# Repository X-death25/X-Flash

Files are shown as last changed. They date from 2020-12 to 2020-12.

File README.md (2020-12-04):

# X-Flash
An Open Source CPLD based Sega Megadrive/Genesis Flash Cart 
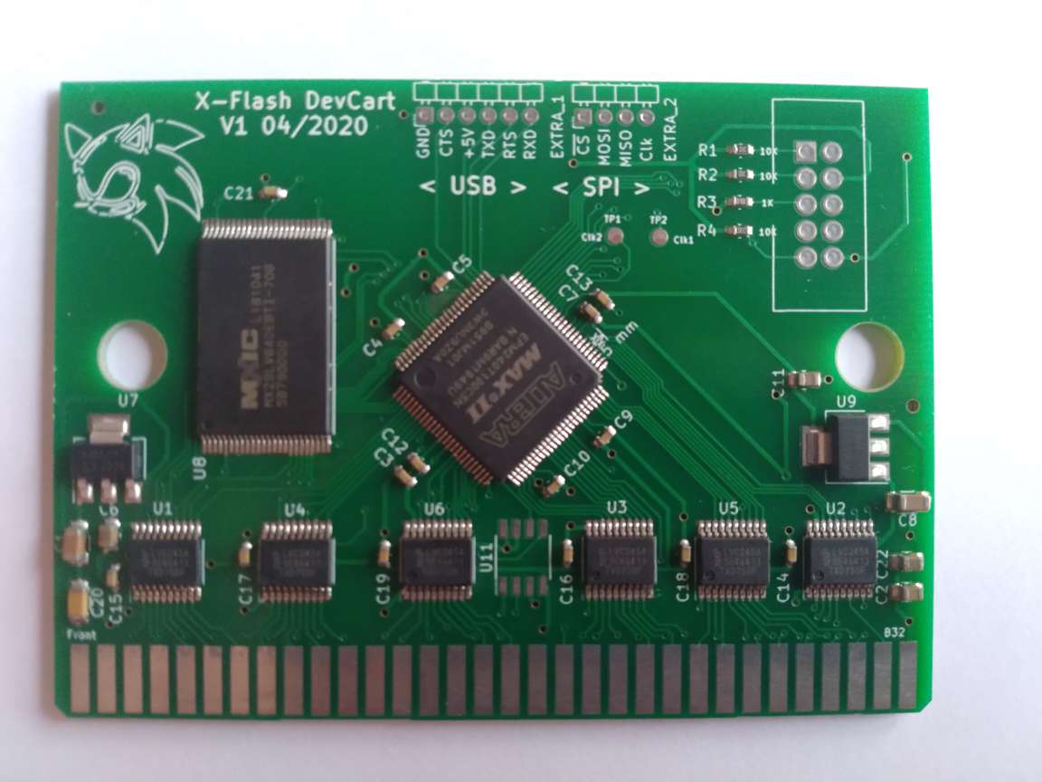
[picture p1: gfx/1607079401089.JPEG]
Xflash_pcb


What is it ?
-----

X-flash is my Sega Megadrive developpement cartridge.
I use it for some research and do all of my hardware test.
It's based on the good old EPM240 and a 64Mb flash memory

Product Feature :
-----

    Rewritable 64 Mb Flash ROM
    192 Macrocells CPLD
    Clean 5V <> 3.3V level shifting
    7 GPIO for user
    Open Source Hardware & Software & PCB

Cartridge supported :
-----
    Classic 32Mb cartridge ( no mapper )

How to use it :
-----

Just flash the needed core into the CPLD and cartridge will works in the same way as an original.
You can reflash memory with any compatible Megadrive reader ( for exemple MD Dumper / Krikkz / Sanni cart Reader )

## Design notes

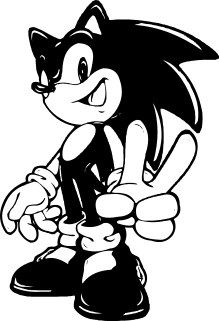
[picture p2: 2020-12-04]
pcb/modules/sonic.png

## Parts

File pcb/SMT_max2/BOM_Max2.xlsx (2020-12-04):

Comment | Designator | Footprint | LCSC Part
Level Shifter | U1,U2,U3,U4,U5,U6 | 74LVC245 | C6082
Flash 64Mb | U8 | MX29LV640 | C30076
Regulateur 3,3V | U7,U9 | AMS1117 3,3V | C6186
MAX2 CPLD | U10 | EPM240T100C5N | C10041
100nF SMD 0603 | C3 ,C4,C5,C7,C9,C10,C12,C13,C14,C15,C16,C17,C18,C19,C21 | 0603_CD | C14663
10µF SMD 1206 | C1,C8 | 0603_CR | C13585
22µF SMD 0805 | C6,C11,C2,C22 | 0603_CR | C45783
100nF SMD 1206 | C20 | 1206_C | C24497
10K SMD 0603 | R1,R2,R4 | R_0603 | C25804
1K SMD 0603 | R3 | R_0603 | C21190

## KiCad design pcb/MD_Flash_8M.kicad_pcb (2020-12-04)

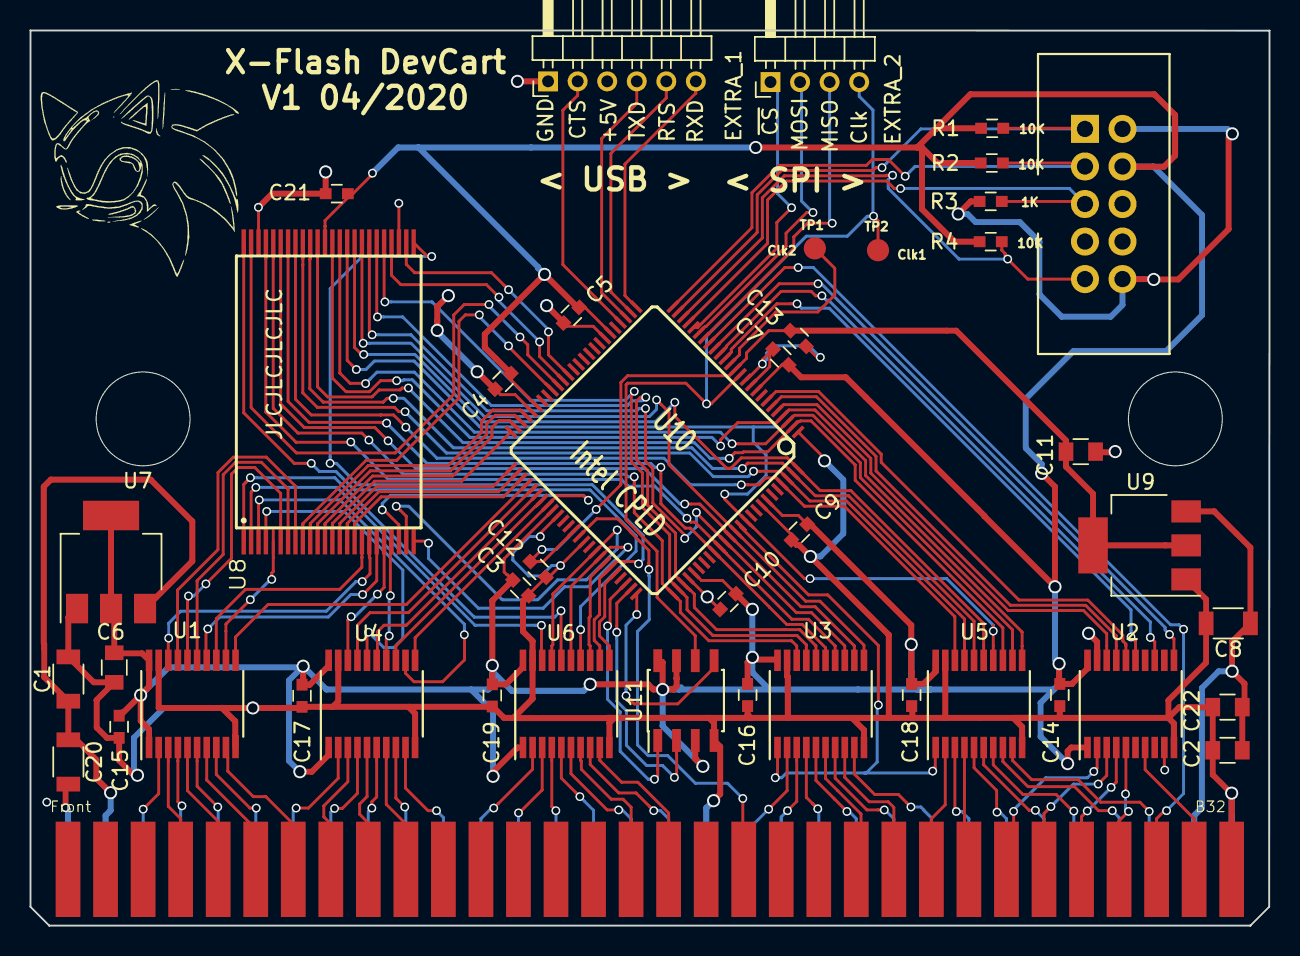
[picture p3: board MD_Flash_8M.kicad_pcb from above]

Board: 2 copper layers, 83.8 x 60.6 mm, 41 parts (0 on the bottom side), 116 nets.

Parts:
C1, C8, C20: 1206_C; C_1206
C2, C6, C11, C22: C_0805
C3, C4, C5, C7, C9, C10, C12, C13, C14, C15, C16, C17, C18, C19, C21: 0603_CD; C_0603
EXTRA_1: Pin_Header_Angled_1x06_Pitch2.00mm
EXTRA_2: Pin_Header_Angled_1x04_Pitch2.00mm
J1: 0; AVR-JTAG-ICE
MD_Connector1: MD_Connector_H; MEGADRIVE_PCB
R1, R2, R3, R4: R_0603; C_0603
U1, U2, U3, U4, U5, U6: 74LVC245; TSSOP-20_4.4x6.5mm_Pitch0.65mm
U7, U9: SOT-223
U8: MX29LV640; S29GL064
U10: Intel CPLD; TQFP_100
U11: AT25xxx; SOIC-8_3.9x4.9mm_Pitch1.27mm

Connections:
5V1: C2.2, C8.1, C22.2, MD_Connector1.A31, U9.3
5V2: C1.1, C20.1, MD_Connector1.A2, U7.3
A1: MD_Connector1.A17, U6.8
A2: MD_Connector1.A15, U6.5
A3: MD_Connector1.A13, U6.3
A4: MD_Connector1.A11, U4.9
A5: MD_Connector1.A9, U4.6
A6: MD_Connector1.A7, U4.2
A7: MD_Connector1.A5, U1.6
A8: MD_Connector1.A3, U1.2
A9: MD_Connector1.B4, U1.3
A10: MD_Connector1.B5, U1.5
A11: MD_Connector1.A4, U1.4
A12: MD_Connector1.A6, U1.8
A13: MD_Connector1.A8, U4.4
A14: MD_Connector1.A10, U4.8
A15: MD_Connector1.A12, U6.2
A16: MD_Connector1.A14, U6.4
A17: MD_Connector1.A16, U6.6
A18: MD_Connector1.B6, U1.7
A19: MD_Connector1.B7, U1.9
A20: MD_Connector1.B8, U4.3
A21: MD_Connector1.B9, U4.5
A22: MD_Connector1.B10, U4.7
ACC: U8.14, U10.51
BUF_Dir: U3.1, U5.1, U10.89
BYTE: U8.47, U10.41
CE_SPI: U10.73, U11.1
Clk_SPI: EXTRA_2.4, U10.12, U11.6
D0: MD_Connector1.A20, U3.3
D1: MD_Connector1.A23, U3.7
D2: MD_Connector1.A26, U5.5
D3: MD_Connector1.A29, U5.8
D4: MD_Connector1.A28, U5.7
D5: MD_Connector1.A25, U5.3
D6: MD_Connector1.A22, U3.5
D7: MD_Connector1.A19, U3.2
D8: MD_Connector1.A21, U3.4
D9: MD_Connector1.A24, U3.9
D10: MD_Connector1.A27, U5.6
D11: MD_Connector1.A30, U5.9
D12: MD_Connector1.B25, U5.4
D13: MD_Connector1.B24, U5.2
D14: MD_Connector1.B23, U3.8
D15: MD_Connector1.B22, U3.6
FA19: U8.16, U10.53
FA20: U8.9, U10.42
FA21: U8.10, U10.47
FA22: U8.13, U10.50
FCE: U8.26, U10.39
FOE: U8.28, U10.40
GND: C1.2, C2.1, C3.1, C4.2, C5.2, C6.2, C7.2, C8.2, C9.2, C10.2, C11.2, C12.1, C13.1, C14.1, C15.2, C16.1, C17.1, C18.1, C19.1, C20.2, C21.1, C22.1, EXTRA_1.1, J1.2, J1.10, MD_Connector1.A1, MD_Connector1.A18, MD_Connector1.A32, MD_Connector1.B32, R3.2, U1.10, U1.19, U2.10, U3.10, U3.19, U4.10, U4.19, U5.10, U5.19, U6.10, U6.19, U7.1, U8.27, U8.46, U9.1, U10.1, U10.10, U10.11, U10.32, U10.46, U10.60, U10.65, U10.79, U10.93, U11.4
MISO: U10.74, U11.2
MOSI: U10.75, U11.5
RY-BY: U8.15, U10.52
TCK: J1.1, R1.1, U10.24
TDI: J1.9, R4.1, U10.23
TDO: J1.3, R2.1, U10.25
TMS: J1.5, R3.1, U10.22
VA1: U6.12, U8.25, U10.70
VA2: U6.15, U8.24, U10.68
VA3: U6.17, U8.23, U10.67
VA4: U4.11, U8.22, U10.58
VA5: U4.14, U8.21
VA6: U4.18, U8.20
VA7: U1.14, U8.19
VA8: U1.18, U8.18
VA9: U1.17, U8.8
VA10: U1.15, U8.7
VA11: U1.16, U8.6
VA12: U1.12, U8.5
VA13: U4.16, U8.4
VA14: U4.12, U8.3
VA15: U6.18, U8.2
VA16: U6.16, U8.1
VA17: U6.14, U8.48
VA18: U1.13, U8.17
VA19: U1.11, U10.54
VA20: U4.17, U10.55
VA21: U4.15, U10.56
VA22: U4.13, U10.57
VCC2: C11.1, C12.2, C13.2, U9.2, U9.4, U10.13, U10.63
VCC3: C3.2, C4.1, C5.1, C6.1, C7.1, C9.1, C10.1, C14.2, C15.1, C16.2, C17.2, C18.2, C19.2, C21.2, J1.4, R1.2, R2.2, R4.2, U1.1, U1.20, U2.1, U2.20, U3.20, U4.1, U4.20, U5.20, U6.1, U6.20, U7.2, U7.4, U8.37, U10.9, U10.31, U10.45, U10.59, U10.80, U10.94, U11.3, U11.7, U11.8
VD0: U3.17, U8.29, U10.77
VD1: U3.13, U8.31, U10.86
VD2: U5.15, U8.33, U10.100
VD3: U5.12, U8.35, U10.3
VD4: U5.13, U8.38, U10.2
VD5: U5.17, U8.40, U10.98
VD6: U3.15, U8.42, U10.84
VD7: U3.18, U8.44, U10.76
VD8: U3.16, U8.30, U10.78
VD9: U3.11, U8.32, U10.88
VD10: U5.14, U8.34, U10.90
VD11: U5.11, U8.36, U10.4
VD12: U5.16, U8.39, U10.99
VD13: U5.18, U8.41, U10.97
VD14: U3.12, U8.43, U10.87
VD15: U3.14, U8.45, U10.85
WE: U8.11, U10.48
~ASEL: MD_Connector1.B26, U2.2
~CE_ROM: MD_Connector1.B17, U6.9
~Mark3: MD_Connector1.B30, U10.18
~OE_ROM: MD_Connector1.B16, U6.7
~Soft_Rst: MD_Connector1.B27, U2.3
~TIME: MD_Connector1.B31, U2.7
~UWR: MD_Connector1.B29, U2.5
~V68K_Rst: U2.11, U10.17
~VASEL: U2.18, U10.5
~VCE: U6.11, U10.71
~VOE: U6.13, U10.69
~VRst: U2.17, U10.6
~VTIME: U2.13, U10.16
~VUWR: U2.15, U10.15
~VWE: U2.16, U10.7
~WE_ROM: MD_Connector1.B28, U2.4
